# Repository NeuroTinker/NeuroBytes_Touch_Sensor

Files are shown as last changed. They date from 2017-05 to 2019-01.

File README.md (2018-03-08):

# NeuroBytes Touch Sensory Neuron
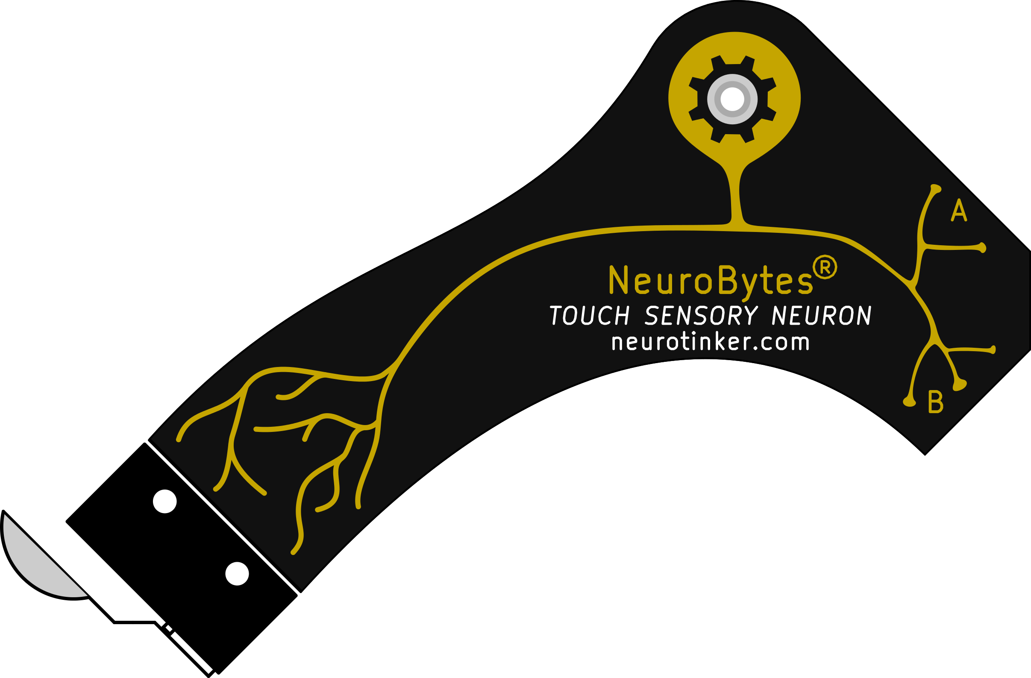
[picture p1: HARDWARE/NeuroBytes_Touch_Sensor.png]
NeuroBytes Touch Sensory Neuron PCB front

The NeuroBytes Touch Sensory Neuron is an open-source hardware neuron simulator designed and sold by [NeuroTinker, LLC](http://www.neurotinker.com/). 

All NeuroBytes products are based on the ST32L0x series of ARM Cortex-M0+ 32-bit microcontrollers. The boards were designed in KiCad and Inkscape and are released under the terms of the Creative Commons Attribution-ShareAlike 4.0 license, available here: http://creativecommons.org/licenses/by-sa/4.0/. The NeuroBytes Touch Sensory Neuron is Certified Open Source Hardware as defined by [OSHWA](https://www.oshwa.org), certification number US000110.


OSHWA Certification

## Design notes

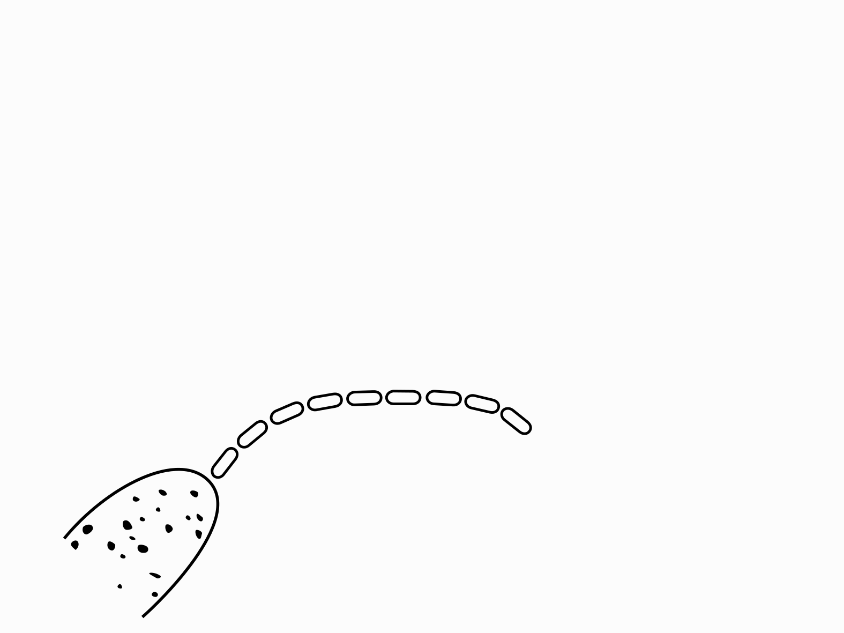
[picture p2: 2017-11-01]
HARDWARE/silk.png

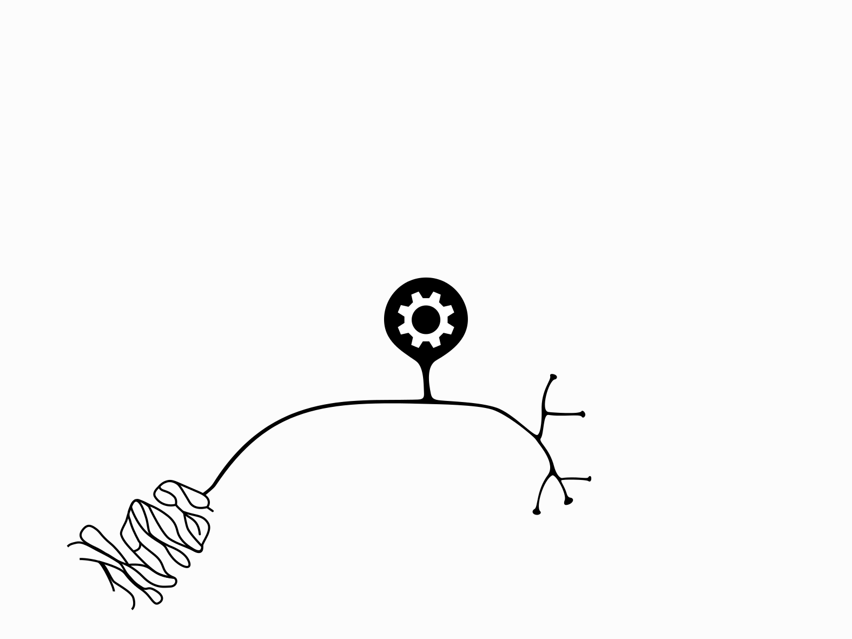
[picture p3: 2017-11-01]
HARDWARE/mask.png

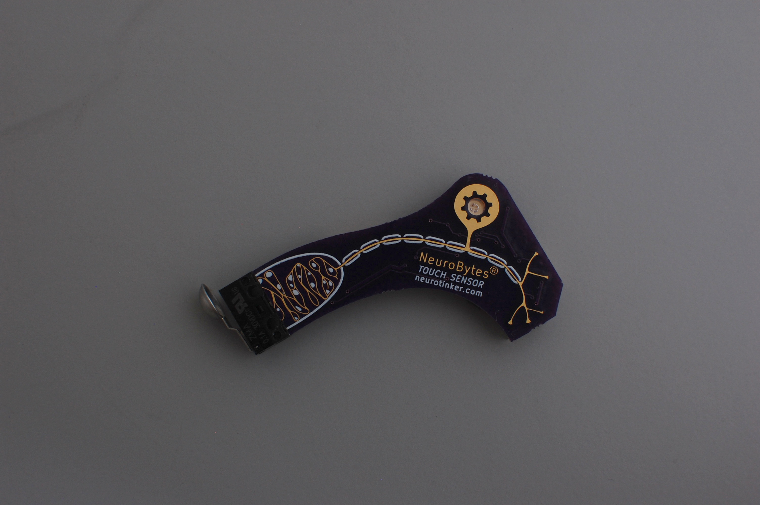
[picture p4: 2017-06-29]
HARDWARE/img_front.JPG

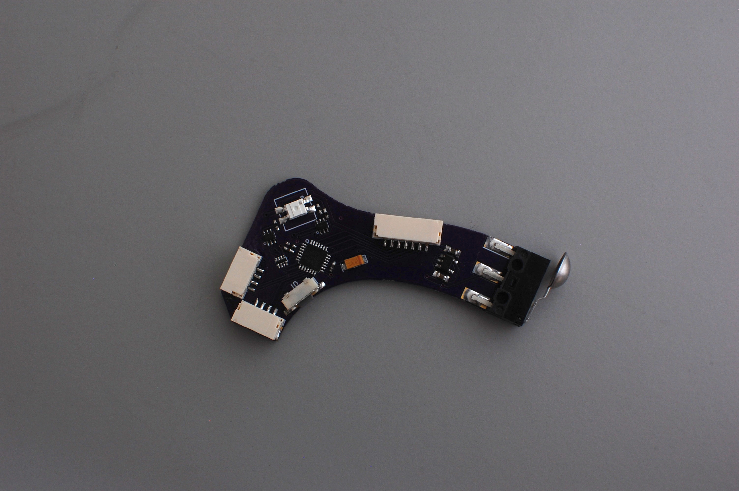
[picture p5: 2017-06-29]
HARDWARE/img_back.JPG

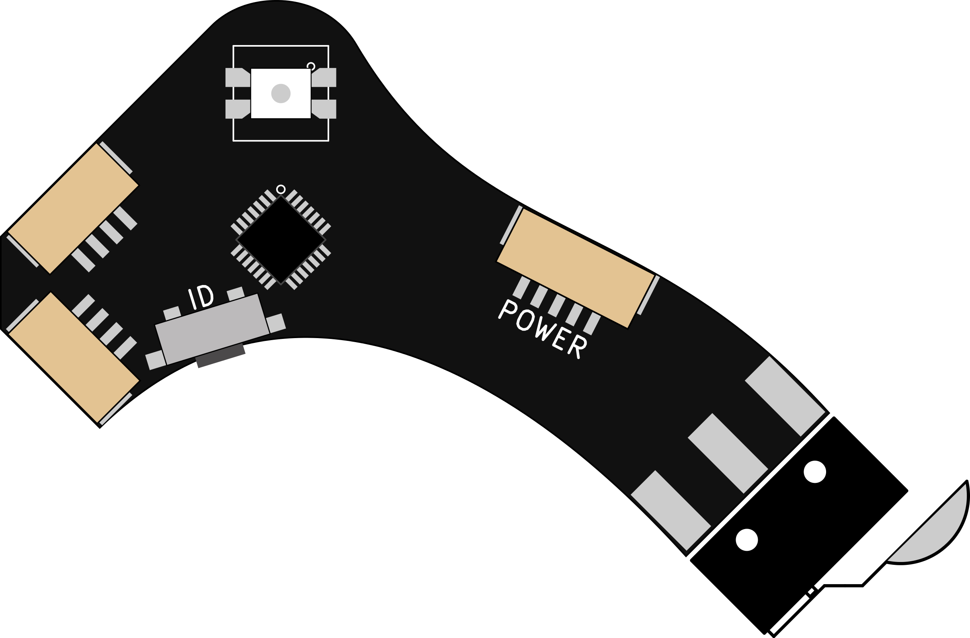
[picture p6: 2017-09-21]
HARDWARE/NeuroBytes_Touch_Sensor_back.png

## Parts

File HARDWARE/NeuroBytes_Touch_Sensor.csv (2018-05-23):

Ref | Qty | Value | Link | Mfr | Mfr Part # | Package | RoHS | Subs Allowed
C1 C4 | 2 | 1u | https://www.digikey.com/product-detail/en/taiyo-yuden/LMK107B7105KA-T/587-1242-2-ND/930594 | Taiyo Yuden | LMK107B7105KA-T | C0603 | Yes | Yes
C5 C3 | 2 | 0u1 | https://www.digikey.com/product-detail/en/taiyo-yuden/LMK105BJ104KV-F/587-1227-2-ND/930579 | Taiyo Yuden | LMK105BJ104KV-F | C0402 | Yes | Yes
C2 | 1 | 10u | https://www.digikey.com/product-detail/en/taiyo-yuden/EMK316B7106KL-TD/587-2395-2-ND/2178914 | Taiyo Yuden | EMK316B7106KL-TD | C1206 | Yes | Yes
D1 | 1 | LED_RABG | https://www.digikey.com/product-detail/en/sunled/XZMDKCBDDG45S-9/1497-1257-2-ND/4902045 | SunLED | XZMDKCBDDG45S-9 | SMT | Yes | No
P6 P7 | 2 | CONN_01X04 | https://www.digikey.com/product-detail/en/jst-sales-america-inc/SM04B-GHS-TB-LF-SN/455-1566-2-ND/807788 | JST | SM04B-GHS-TB(LF)(SN) | JST_GH_4-POS | Yes | No
P1 | 1 | JST_GH_5-pos | https://www.digikey.com/product-detail/en/jst-sales-america-inc/SM05B-GHS-TB-LF-SN/455-1567-2-ND/807789 | JST | SM05B-GHS-TB(LF)(SN) | SMT | Yes | No
Q1 Q2 Q3 | 3 | MMBT3904 | https://www.digikey.com/product-detail/en/micro-commercial-co/MMBT3904-TP/MMBT3904TPMSTR-ND/717280 | Micro Commercial Co | MMBT3904-TP | SOT23-3L | Yes | Yes
R1 | 1 | 150 | https://www.digikey.com/product-detail/en/yageo/RC0402FR-07150RL/311-150LRCT-ND/729490 | Yageo | RC0402FR-07150RL | R0402 | Yes | Yes
R2 R3 | 2 | 100 | https://www.digikey.com/product-detail/en/yageo/RC0402FR-07100RL/311-100LRTR-ND/726527 | Yageo | RC0402FR-07100RL | R0402 | Yes | Yes
R4 | 1 | JMP | https://www.digikey.com/product-detail/en/yageo/RC0402JR-070RL/311-0.0JRTR-ND/726406 | Yageo | RC0402JR-070RL | R0402 | Yes | Yes
R5 R6 R7 | 3 | 1k | https://www.digikey.com/product-detail/en/yageo/RC0402FR-071KL/311-1.00KLRTR-ND/726513 | Yageo | RC0402FR-071KL | R0402 | Yes | Yes
SW1 | 1 | SW_PUSH | https://www.digikey.com/product-detail/en/e-switch/TL3330AF130QG/EG4388TR-ND/1426835 | E-Switch | TL3330AF130QG | SMT | Yes | No
SW2 | 1 | SW_SNAP_ACTION | https://www.digikey.com/product-detail/en/c-k/ZMA00A080S06PC/CKN10156-ND/2044492 | C&K | ZMA00A080S06PC | THT (SMT side mtg) | Yes | No
U1 | 1 | STM32L011Gx | http://www.mouser.com/ProductDetail/STMicroelectronics/STM32L011G4U6/ | ST Microelectronics | STM32L011G4U6 | UFQFPN28 | Yes | No
U2 | 1 | 3v3 LDO | https://www.digikey.com/product-detail/en/on-semiconductor/NCP114BSN330T1G/NCP114BSN330T1GOSTR-ND/6560606 | ON Semiconductor | NCP114BSN330T1G | SOT23-5L | Yes | Yes
BOM made with KICAD_BOM_WIZARD (https://github.com/HashDefineElectronics/KiCad_BOM_Wizard.git)
Generated Wed 23 May 2018 05:36:58 PM CDT

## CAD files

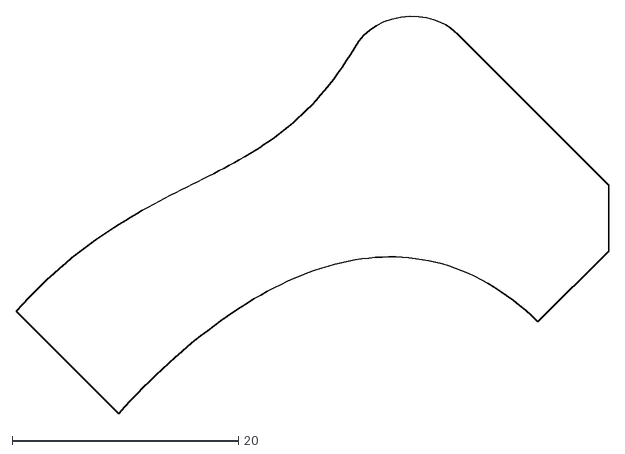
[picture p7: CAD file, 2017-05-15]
HARDWARE/NeuroBytes_Touch_Sensor.dxf
52.3 x 35.1

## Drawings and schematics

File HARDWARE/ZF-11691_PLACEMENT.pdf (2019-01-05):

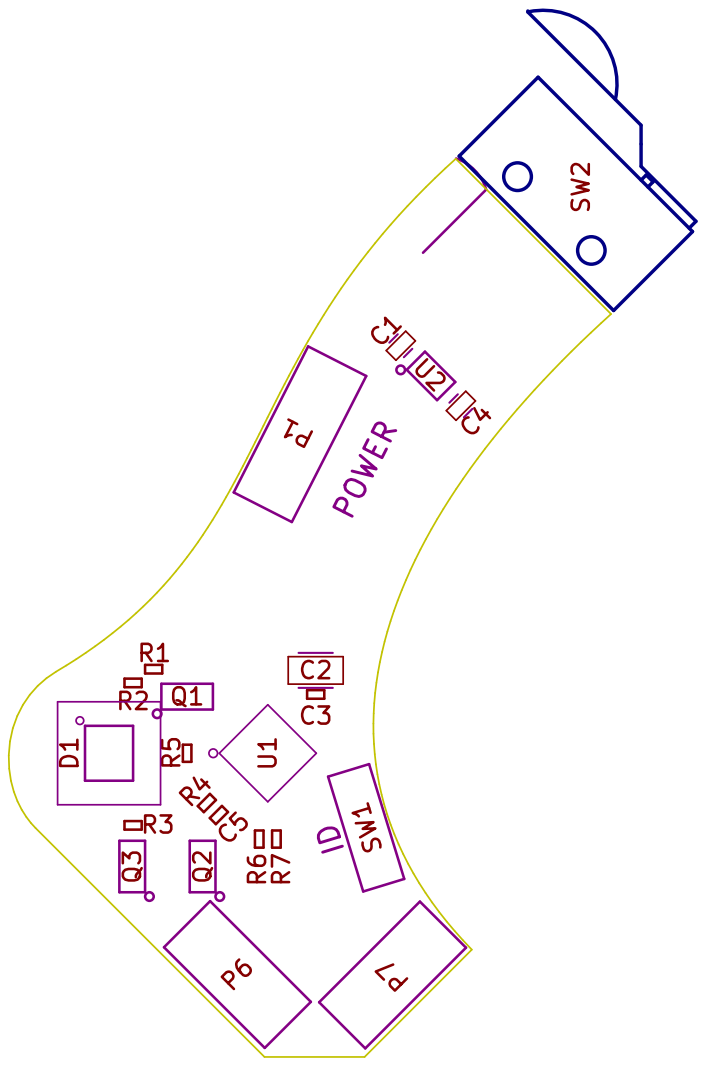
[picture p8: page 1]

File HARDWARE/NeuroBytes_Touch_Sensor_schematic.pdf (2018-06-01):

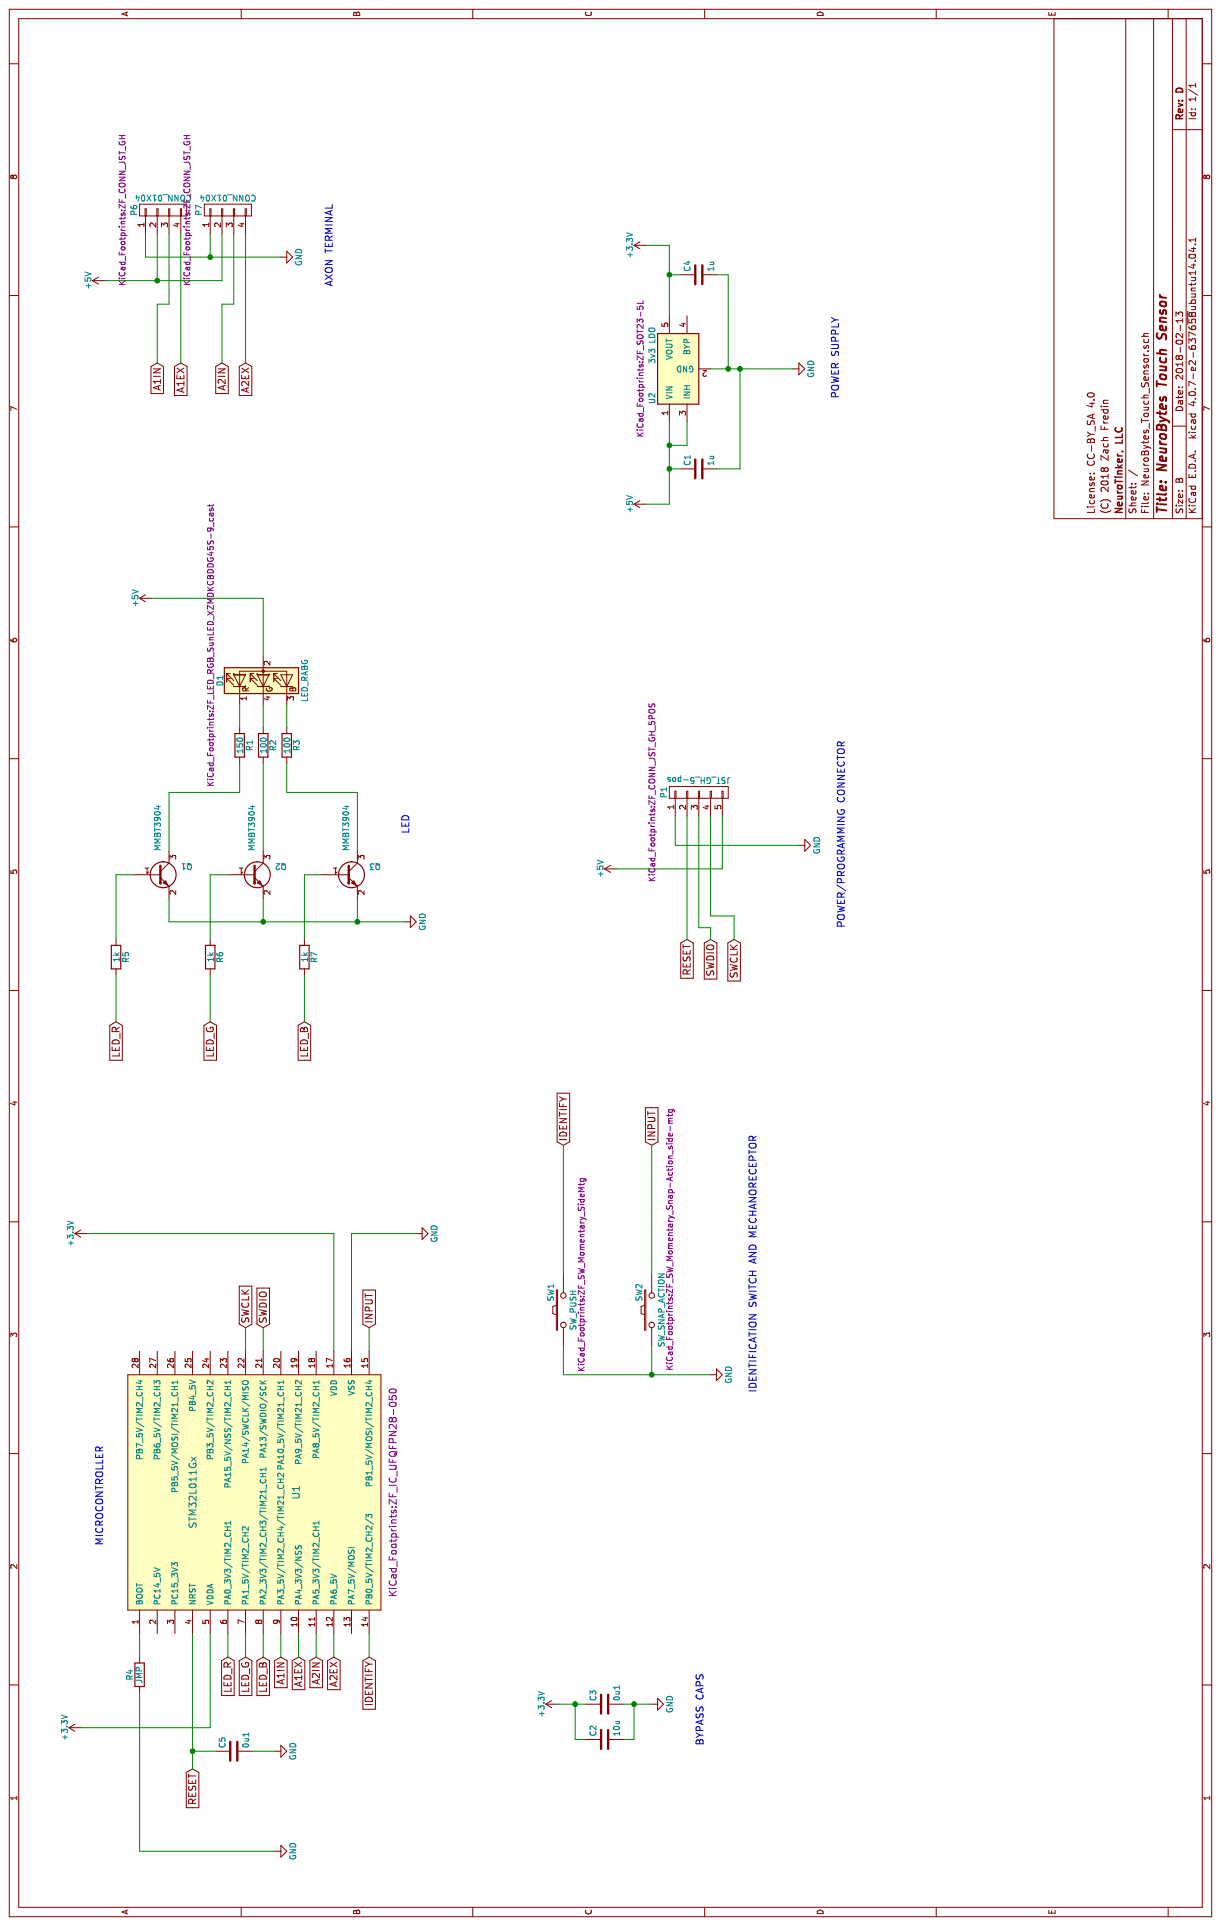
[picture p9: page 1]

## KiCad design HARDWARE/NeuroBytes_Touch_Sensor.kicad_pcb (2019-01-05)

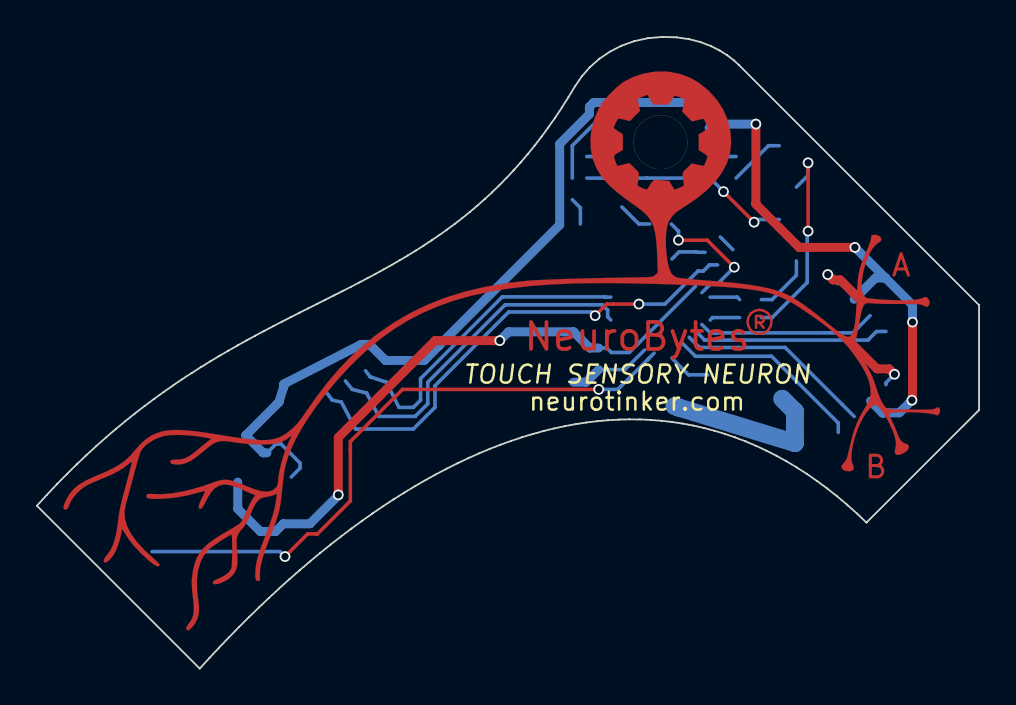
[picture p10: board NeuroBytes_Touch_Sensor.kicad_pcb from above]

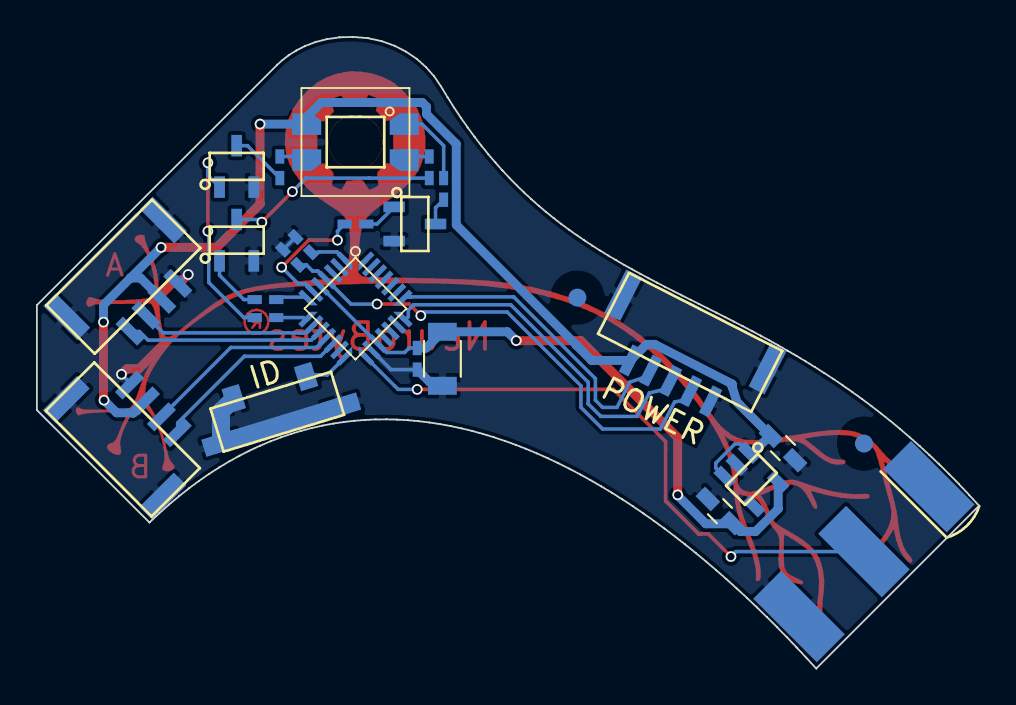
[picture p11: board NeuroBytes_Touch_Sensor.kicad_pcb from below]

Board: 2 copper layers, 52.3 x 35.1 mm, 23 parts (23 on the bottom side), 25 nets.

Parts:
C1, C4: 1u; C_0603_HandSoldering
C2: 10u; C_1206
C3, C5: 0u1; ZF_SMD_NonPol_0402_cap
D1: LED_RABG; ZF_LED_RGB_SunLED_XZMDKCBDDG45S-9_cast
P1: JST_GH_5-pos; ZF_CONN_JST_GH_5POS
P6, P7: CONN_01X04; ZF_CONN_JST_GH
Q1, Q2, Q3: MMBT3904; ZF_SOT23-3L
R1: 150; ZF_SMD_NonPol_0402
R2, R3: 100; ZF_SMD_NonPol_0402
R4: JMP; ZF_SMD_NonPol_0402
R5, R6, R7: 1k; ZF_SMD_NonPol_0402
SW1: SW_PUSH; ZF_SW_Momentary_SideMtg
SW2: SW_SNAP_ACTION; ZF_SW_Momentary_Snap-Action_side-mtg
U1: STM32L011Gx; ZF_IC_UFQFPN28-050
U2: 3v3 LDO; ZF_SOT23-5L

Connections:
+3V3: C2.1, C3.1, C4.1, U1.5, U1.17, U2.5
+5V: C1.1, D1.2, P1.5, P6.2, P7.2, U2.1, U2.3
A1EX: P6.4, U1.10
A1IN: P6.3, U1.9
A2EX: P7.4, U1.12
A2IN: P7.3, U1.11
GND: C1.2, C2.2, C3.2, C4.2, C5.2, P1.1, P6.1, P7.1, Q1.2, Q2.2, Q3.2, R4.1, SW1.1, SW2.1, U1.16, U2.2
IDENTIFY: SW1.2, U1.14
INPUT: SW2.2, U1.15
LED_B: R7.2, U1.8
LED_G: R6.2, U1.7
LED_R: R5.2, U1.6
unnamed: D1.1, R1.1
unnamed: D1.3, R3.1
unnamed: D1.4, R2.1
unnamed: Q1.1, R5.1
unnamed: Q1.3, R1.2
unnamed: Q2.1, R6.1
unnamed: Q2.3, R2.2
unnamed: Q3.1, R7.1
unnamed: Q3.3, R3.2
unnamed: R4.2, U1.1
RESET: C5.1, P1.2, U1.4
SWCLK: P1.4, U1.22
SWDIO: P1.3, U1.21

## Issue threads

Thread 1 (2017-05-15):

Need separate axons

jrwhite, 2017-05-15:
The axons currently share inhibitory/excitatory lines. Protocol implementation will improve fi these are separated.

jrwhite, 2017-05-16:
Schematic has been updated with latest board rev which has separate axons.
False alarm!

Closed 2017-05-16.

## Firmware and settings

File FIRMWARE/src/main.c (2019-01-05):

#define BUFSIZ 32

#include <libopencm3/stm32/rcc.h>
#include <libopencm3/stm32/gpio.h>
#include <libopencm3/stm32/timer.h>
#include <libopencm3/cm3/nvic.h>
#include <libopencm3/cm3/systick.h>
#include <libopencm3/stm32/exti.h>
#include <libopencm3/stm32/usart.h>

#include "HAL.h"
#include "comm.h"
#include "neuron.h"

#define BLINK_TIME			40
#define DATA_TIME			10
#define DEND_PING_TIME		200 // 1000 ms
#define	NID_PING_TIME		200 // 1000 ms
#define SEND_PING_TIME		80
#define BUTTON_PRESS_TIME	2
#define BUTTON_HOLD_TIME    100
#define LPUART_SETUP_TIME	100
#define CHANGE_NID_TIME 	200
#define MECHANORECEPTOR_PRESS_TIME	2
#define MECHANORECEPTOR_ADAPT_START	35
#define MECHANORECEPTOR_ADAPT_END	150

// #define DBG

int main(void)
{
	uint8_t		i;

	// counters
	uint32_t	blink_time = 0; // counter for LED blink due to NID command
	uint16_t	data_time = 0; // counter for sending data to NID
	uint16_t	send_ping_time = 0; // counter for sending a downstream ping
	uint16_t	fire_delay_time = 0;
	int16_t 	depression_time = 0;
	uint8_t		fire_flag = 0;
	uint8_t		change_nid_time = 0;
	int16_t		fire_data = 0; // hack to make sure a pulse sends peak neuron potential and hyperpolarization  data
	uint16_t	fire_delay_time_reset = FIRE_DELAY_TIME;
	fire_delay_time_reset = 40; // temporary
	uint16_t	fire_delay_overflow = 0; // used if firing period is less than delay time.
	uint16_t	lpuart_setup_time = 0;

	// button debounce variables
	uint16_t	button_press_time = 0; 
	uint8_t		button_armed = 0;
	uint16_t	button_status = 0;

	uint16_t	mechanoreceptor_press_time = 0;
	uint16_t	mechanoreceptor_status = 0;
	uint32_t	mechanoreceptor_adapt_count = 0;
	uint32_t 	mechanoreceptor_adapt_reset = 0;

	message_t	message; // staging variable for constructing messages to send to the communications routine

	int32_t joegenta = 0;

	//char output[10] = "test";

	// initialize neuron
	neuron_t 	neuron;
	neuronInit(&neuron);

	neuron.dendrites[0].magnitude = 15000;
	neuron.dendrites[0].base_magnitude = 15000;

	// initialize communication buffers
	commInit();

	// setup hardware
	clock_setup();
	systick_setup(); // systick in microseconds
	gpio_setup();
	tim_setup();

	// main processing routine	
	for(;;)
	{
		if (main_tick == 1 && pause_flag == 0){
			// main tick every 5 ms
			main_tick = 0;
			//gpio_set(PORT_AXON1_EX, PIN_AXON1_EX);

			// check to see if nid ping hasn't been received in last NID_PING_TIME ticks
			if (nid_ping_time > 0){
				nid_ping_time -= 1;
				if (nid_ping_time == 0){
					// nid no longer connected
					nid_distance = 100; // reset nid_keep_alive
					nid_pin = 0; // clear the nid pin
					nid_pin_out = 0;
					nid_i = NO_NID_I;
				}
			}
			
			if (change_nid_time++ > CHANGE_NID_TIME){
				change_nid_time = 0;
				closer_distance = nid_distance;
				closer_ping_count = 0;
			}

			// send a downstream ping every SEND_PING_TIME ticks
			if (send_ping_time++ > SEND_PING_TIME){
				// send downstream ping through axon
				addWrite(DOWNSTREAM_BUFF, downstream_ping_message);
				send_ping_time = 0;
			}

			if (lpuart_setup_time < LPUART_SETUP_TIME){
				lpuart_setup_time += 1;
			} else if (lpuart_setup_time == LPUART_SETUP_TIME){
				lpuart_setup_time += 1;
				#ifndef DBG
				lpuart_setup();
				#endif
			}

			/*
				nid_channel is the current channel, if any, that the NeuroByte is using to communicate
				with the NID. nid_channel should be cleared when NID tries to set a new NeuroByte to 
				identify_channel.

				The communication routine sets identify_time to zero when a new identify command is received.
			*/

			// check for clear channel command
			if (identify_time < IDENTIFY_TIME){
				if (identify_time == 0){
					if ((identify_channel == 0) || (identify_channel == nid_channel)){
						nid_channel = 0;
					}
				}
				identify_time += 1;
			}

			// check buttons
			button_status = gpio_get(PORT_IDENTIFY, PIN_IDENTIFY); 
			mechanoreceptor_status = gpio_get(PORT_MECHANORECEPTOR, PIN_MECHANORECEPTOR);

			// if identify button is pressed and identify_time < IDENTIFY_TIME (i.e. NID sent 'identify'' message), set new nid_channel
			if (button_status == 0){
				// debounce
				button_press_time += 1;
				if (button_press_time >= BUTTON_HOLD_TIME){
					button_armed = 2;
					// blink_flag = 1;
				} else if (button_press_time >= BUTTON_PRESS_TIME){
					button_armed = 1;
				}
			} else{
				// button not pressed
				if (button_armed == 0){
					button_press_time = 0;
				} else if (button_armed == 1 && nid_i != NO_NID_I){
					nid_channel = identify_channel;
					message.length = 32;
					message.message = (((uint32_t) DATA_TYPE_MESSAGE) | (((uint32_t) nid_channel) << 22));
					message.message |=  ((const uint16_t) (getFingerprint()));
					addWrite(NID_BUFF, (const message_t) message);
					identify_time = 1;
					button_armed = 0;
				} else if (button_armed == 2){
					// put button held logic here
					button_armed = 0;
				}
				button_press_time = 0;
			}
		
			if (mechanoreceptor_status == 0){
				//debounce
				mechanoreceptor_press_time += 1;
				if (mechanoreceptor_press_time >= MECHANORECEPTOR_PRESS_TIME){
					if (mechanoreceptor_adapt_count == 0) {
						neuron.dendrites[0].type = EXCITATORY;
						neuron.dendrites[0].state = ON;
						neuron.dendrites[0].pulse_time = 0;	
					}
					// mechanoreceptor_adapt_count++;
					if (mechanoreceptor_adapt_count > mechanoreceptor_adapt_reset) {
						mechanoreceptor_adapt_count = 0;
						if (mechanoreceptor_adapt_reset < MECHANORECEPTOR_ADAPT_END) {
							mechanoreceptor_adapt_reset <<= 4;
							mechanoreceptor_adapt_reset /= 15;
						}
					}			
				}	
			} else{
				mechanoreceptor_adapt_reset = MECHANORECEPTOR_ADAPT_START;
				mechanoreceptor_adapt_count = 0;
				mechanoreceptor_press_time = 0;
			}	

			// send current membrane potential to NID if currently identified by NID
			if (nid_channel != 0){
				// send data every DATA_TIME ticks
				if (data_time++ > DATA_TIME){
					if (fire_data > 0){
						if (fire_data == 1){
							message.message = (((uint32_t) DATA_MESSAGE)) | ((uint16_t) HYPERPOLARIZATION);
							fire_data = 0;						
						} else {
							message.message = (((uint32_t) DATA_MESSAGE)) | ((uint16_t) fire_data);	
							fire_data = 1;						
						}
					} else {
						message.message = (((uint32_t) DATA_MESSAGE)) | ((uint16_t) neuron.potential);						
					}
					data_time = 0;
					message.length = 32;
					message.message |= (nid_channel << 22);
					addWrite(NID_BUFF,(const message_t) message);
				}
			}

			// decay old dendrite contributions to the membrane potential
			dendriteDecayStep(&neuron);
			// decay the firing potential
			membraneDecayStep(&neuron);

			// current membrane potential comes from dendrites and any left over firing potential
			neuron.potential = calcNeuronPotential(&neuron);
			neuron.potential += neuron.fire_potential;
			neuron.fire_potential += neuron.leaky_current;

			// if membrane potential is greater than threshold, fire
			if (neuron.potential > MEMBRANE_THRESHOLD){
				// fire for determined pulse width
				neuron.state = FIRE;
				neuron.fire_potential = HYPERPOLARIZATION;
				neuron.fire_time = PULSE_LENGTH;
				for (i=0; i<NUM_DENDS; i++){
					neuron.dendrites[i].current_value = 0;
					neuron.dendrites[i].state = OFF;
				}

				fire_data = neuron.potential; // hack to send fire data to NID

				// send downstream pulse
				if (fire_delay_time == 0){
					fire_delay_time = fire_delay_time_reset;
					fire_delay_overflow = 0;
				} else {
					fire_delay_overflow = fire_delay_time_reset - fire_delay_time;
				}
				fire_flag = 1;
			} else if (neuron.potential < HYPERPOLARIZATION) {
				neuron.potential = HYPERPOLARIZATION;
			}

			if (fire_delay_time > 0){
				fire_delay_time -= 1;
			} else if (fire_flag == 1){
				if (fire_delay_overflow > 0)
					fire_delay_time = fire_delay_overflow; // TODO: make this an actual FIFO buffer of fire timings
				fire_flag = 0;
				addWrite(DOWNSTREAM_BUFF, pulse_message);
			}

			/*
				LED is either:
				-blinking due to NID message (blink_flag is set)
				-full white if neuron is firing
				-in an RGB state mapped to membrane potential
			*/
			
			if (blink_flag != 0){
				setLED(200,0,300);
				blink_time = 1;
				blink_flag = 0;
			} else if (blink_time > 0){
				if (++blink_time == BLINK_TIME){
					setLED(200,0,200);
					blink_time = 0;
				}
			} else if (neuron.state == FIRE){
				neuron.fire_time -= 1;
				if (neuron.fire_time == 0){
					neuron.state = INTEGRATE;
				}
				if (neuron.learning_state == HEBB){
					// needs to vary between 50 and 320
					joegenta /= 256;
					joegenta *= 3;
					joegenta += 100;
					if (joegenta > 350) joegenta = 350;
					setLED(joegenta, joegenta, joegenta);
				} else{
					LEDFullWhite();
				}
			} else if (neuron.state == INTEGRATE){
				if (neuron.potential > 10000){
					setLED(200,0,0);
				} else if (neuron.potential > 0){
					setLED(neuron.potential / 50, 200 - (neuron.potential / 50), 0);
				} else if (neuron.potential < -10000){
					setLED(0,0, 200);
				} else if (neuron.potential < 0){
					setLED(0, 200 + (neuron.potential / 50), -1 * neuron.potential / 50);
				} else{
					setLED(0,200,0);
				}
			}
		}
	}
}

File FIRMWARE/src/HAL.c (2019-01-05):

#include "HAL.h"

volatile uint8_t tick = 0;
volatile uint8_t main_tick = 0;
volatile uint8_t read_tick = 0;

volatile uint16_t active_input_pins[NUM_INPUTS] = {[0 ... NUM_INPUTS-1] = 0};

volatile uint8_t active_input_tick[NUM_INPUTS] = {[0 ... NUM_INPUTS-1] = 0};

volatile uint16_t active_output_pins[NUM_INPUTS] = {PIN_AXON1_EX, PIN_AXON2_EX};

volatile uint32_t dendrite_pulses[NUM_DENDS] = {[0 ... NUM_DENDS-1] = 0};
volatile uint8_t dendrite_pulse_count = 0;

/* 

All available input pins are:

PIN_AXON1_IN,
PIN_AXON2_IN,

*/

uint32_t active_input_ports[NUM_INPUTS] = {
    PORT_AXON1_IN,
    PORT_AXON2_IN,
};

uint32_t active_output_ports[NUM_INPUTS] = {
    PORT_AXON1_EX,
    PORT_AXON2_EX,
};

const uint16_t complimentary_pins[NUM_INPUTS] = {
    PIN_AXON1_EX,
    PIN_AXON2_EX,
};

const uint32_t complimentary_ports[NUM_INPUTS] = {
    PORT_AXON1_EX,
    PORT_AXON2_EX,
};

volatile uint8_t dendrite_pulse_flag[NUM_INPUTS] = {[0 ... NUM_INPUTS-1] = 0};
volatile uint8_t dendrite_ping_flag[NUM_INPUTS] = {[0 ... NUM_INPUTS-1] = 0};


static const uint32_t fingerprint[3] __attribute__((section (".fingerprint"))) __attribute__ ((__used__)) = {
	5, // device id
	2, // firmware version
	0  // unique id
};

bool checkVersion(device_id, version) {return (device_id == fingerprint[0]) && (version = fingerprint[1]) ? true : false;}

void clock_setup(void)
{
	// STM32F0 command:	rcc_clock_setup_in_hsi_out_48mhz();
	rcc_set_sysclk_source(RCC_HSI16);
	rcc_osc_on(RCC_HSI16);
}

void sys_tick_handler(void)
{
    if (++tick >= 50){
		main_tick = 1;
		tick = 0;
	}

	if (read_tick++ >= 2){
		writeBit();
		read_tick = 0;
	}

	readBit(read_tick);
	
    MMIO32((TIM21_BASE) + 0x10) &= ~(1<<0); //clear the interrupt register
}

void systick_setup()
{
    systick_set_clocksource(STK_CSR_CLKSOURCE_EXT);
    STK_CVR = 0;
    //systick_set_reload(2 * xms);
	systick_set_reload(180); //180
    systick_counter_enable();
    systick_interrupt_enable();
}

void gpio_setup(void)
{
	/*	Enable GPIO clocks */
	rcc_periph_clock_enable(RCC_GPIOA);
	rcc_periph_clock_enable(RCC_GPIOB);
	rcc_periph_clock_enable(RCC_GPIOC);

	rcc_peripheral_enable_clock(&RCC_APB2ENR, RCC_APB2ENR_SYSCFGEN); // this line took a long time


	/*	Set up LED pins, NeuroBytes v1.01:
		Alternative Function Mode with no pullup/pulldown
		Output options: push-pull, high speed
		PIN_R_LED (PA2): AF2, TIM2_CH3
		PIN_G_LED (PA5): AF5, TIM2_CH1
		PIN_B_LED (PA3): AF2, TIM2_CH4 
	*/
	
	gpio_mode_setup(PORT_LED, GPIO_MODE_AF, GPIO_PUPD_NONE, PIN_R_LED | PIN_G_LED | PIN_B_LED);
	gpio_set_output_options(PORT_LED, GPIO_OTYPE_PP, GPIO_OSPEED_HIGH, PIN_R_LED | PIN_G_LED | PIN_B_LED);
	gpio_set_af(PORT_LED, GPIO_AF2, PIN_R_LED | PIN_G_LED);
	gpio_set_af(PORT_LED, GPIO_AF2, PIN_B_LED);
	
	/* 
		Setup axon pins:
		Axon Excitatory PA10 TIM21_CH1	(temporarily output)
		Axon Inhibitory PA9  TIM21_CH2	(temporarily input)
	*/
	
	gpio_mode_setup(PORT_AXON1_EX, GPIO_MODE_OUTPUT, GPIO_PUPD_PULLDOWN, PIN_AXON1_EX);
	gpio_mode_setup(PORT_AXON1_IN, GPIO_MODE_INPUT, GPIO_PUPD_NONE, PIN_AXON1_IN);
	gpio_mode_setup(PORT_AXON2_EX, GPIO_MODE_OUTPUT, GPIO_PUPD_PULLDOWN, PIN_AXON2_EX);
	gpio_mode_setup(PORT_AXON2_IN, GPIO_MODE_OUTPUT, GPIO_PUPD_PULLDOWN, PIN_AXON2_IN);
	
	setAsInput(PORT_AXON1_IN, PIN_AXON1_IN);
	setAsOutput(PORT_AXON1_EX, PIN_AXON1_EX);
	setAsInput(PORT_AXON2_IN, PIN_AXON2_IN);
	setAsOutput(PORT_AXON2_EX, PIN_AXON2_EX);
	
	gpio_mode_setup(PORT_MECHANORECEPTOR, GPIO_MODE_INPUT, GPIO_PUPD_PULLUP, PIN_MECHANORECEPTOR);
	gpio_mode_setup(PORT_IDENTIFY, GPIO_MODE_INPUT, GPIO_PUPD_PULLUP, PIN_IDENTIFY);
	
	nvic_enable_irq(NVIC_EXTI0_1_IRQ);
	nvic_enable_irq(NVIC_EXTI2_3_IRQ);
	nvic_enable_irq(NVIC_EXTI4_15_IRQ);

	nvic_set_priority(NVIC_EXTI0_1_IRQ, 0);
	nvic_set_priority(NVIC_EXTI2_3_IRQ, 0);
	nvic_set_priority(NVIC_EXTI4_15_IRQ, 0);
}

void lpuart_setup(void)
{
	// seutp lpuart interface (for communicating with NID)
	// NOTE: this ocnverts the swd interface to lpuart so debugging with swd will be disables
	rcc_periph_clock_enable(RCC_LPUART1);

	gpio_mode_setup(PORT_LPUART1_RX, GPIO_MODE_AF, GPIO_PUPD_NONE, PIN_LPUART1_RX);
	gpio_mode_setup(PORT_LPUART1_TX, GPIO_MODE_AF, GPIO_PUPD_NONE, PIN_LPUART1_TX);

	gpio_set_af(PORT_LPUART1_RX, GPIO_AF6, PIN_LPUART1_RX);
	gpio_set_af(PORT_LPUART1_TX, GPIO_AF6, PIN_LPUART1_TX);

	USART_BRR(LPUART1) = 0x1A0AA; // 38400 baud
	usart_set_databits(LPUART1, 8);  // USART_CR1_M
	usart_set_stopbits(LPUART1, USART_STOPBITS_1); //USART_CR2_STOP
	usart_set_mode(LPUART1, USART_MODE_TX_RX); //USART_CR1_RE USART_CR1_TE
	usart_set_parity(LPUART1, USART_PARITY_NONE);// USART_CR1_PS USART_CR1_PCE
	usart_set_flow_control(LPUART1, USART_FLOWCONTROL_NONE); // USART_CR3_RTSE USART_CR3_CTSE

	usart_enable(LPUART1); // USART_CR1_UE

	// enable interrupts
	nvic_enable_irq(NVIC_LPUART1_IRQ);
	usart_enable_rx_interrupt(LPUART1); // USART_CR1_RXNEIE
    USART_CR1(LPUART1) |= USART_CR1_RE;
    USART_CR1(LPUART1) |= USART_CR1_TE;
}

void lpuart1_isr(void)
{
    if ((USART_ISR(LPUART1) & USART_ISR_RXNE) != 0){
        readNID();
        USART_RQR(LPUART1) = 0b1000;
        USART_CR1(LPUART1) |= USART_CR1_RE;
    } else if ((USART_ISR(LPUART1) & USART_ISR_TXE) != 0){
        /* USART_CR1(LPUART1) |= USART_CR1_TE; */
        writeNID();
        USART_RQR(LPUART1) |= USART_RQR_TXFRQ;
    }
    USART_ICR(LPUART1) = USART_ISR(LPUART1);
}

void setAsInput(uint32_t port, uint32_t pin)
{
	// setup gpio as an input pin
	gpio_mode_setup(port, GPIO_MODE_INPUT, GPIO_PUPD_PULLDOWN, pin);
	gpio_set_output_options(port, GPIO_OTYPE_PP, GPIO_OSPEED_LOW, pin);

	// setup interrupt for the pin going high
	exti_select_source(pin, port);
	exti_set_trigger(pin, EXTI_TRIGGER_RISING);
	exti_enable_request(pin);
	exti_reset_request(pin);
}

void setAsOutput(uint32_t port, uint32_t pin)
{
	// disable input interrupts
	exti_disable_request(pin);

	// setup gpio as an output pin. pulldown
	gpio_mode_setup(port, GPIO_MODE_OUTPUT, GPIO_PUPD_PULLDOWN, pin);
}

// working interrupt pins: 0,1,3,4,6,7

/*
	Each input's ISR tells the communications program that the input is active (getting a message).
	For dendrite inputs, the ISR also tells the neuron program if the input is excitatory or inhibitory and then toggles input/output
*/

void exti0_1_isr(void)
{
	// interrupt handler for pins 0,1
}

void exti2_3_isr(void)
{
	// interrupt handler for pins 2,3
	if ((EXTI_PR & PIN_AXON1_IN) != 0){
		// pin 3
		ACTIVATE_INPUT(0, PIN_AXON1_IN);
		EXTI_PR |= PIN_AXON1_IN;
	}
}

void exti4_15_isr(void)
{
	// interrupt handler for pins 4-15
	//setLED(0,0,200);
	//gpio_toggle(PORT_AXON_OUT, PIN_AXON_OUT);
	if ((EXTI_PR & PIN_AXON2_IN) != 0){
		// pin 5
		active_input_pins[1] = PIN_AXON2_IN;
		ACTIVATE_INPUT(1, PIN_AXON2_IN);
		EXTI_PR |= PIN_AXON2_IN;
	}
}
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

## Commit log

2017-04-24 Initial commit -- first rev HW and test FW.
    [NeuroBytes_Touch_Sensor.dxf, NeuroBytes_Touch_Sensor.kicad_pcb, NeuroBytes_Touch_Sensor.sch]
2017-05-15 added schematic library submodule
2017-05-15 Board rev2. Simplified PCB outline and modified axon graphics a bit.
    [NeuroBytes_Touch_Sensor.dxf, NeuroBytes_Touch_Sensor.kicad_pcb, NeuroBytes_Touch_Sensor.sch]
2017-05-15 updated firmware for new board revision
2017-05-16 Updated PCB footprints to proper rotations. Added fab documentation to PCB file. Generated Gerber files, drill file, and placement file. Generated and filled in BOM. Added switch graphic to PCB dwgs 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
    [NeuroBytes_Touch_Sensor-B.Cu.gbr, NeuroBytes_Touch_Sensor-B.Fab.gbr, NeuroBytes_Touch_Sensor-B.Mask.gbr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]
2017-05-17 Minor Gerber file updates. Removed paste from SW2 (snap-action) footprint.
    [NeuroBytes_Touch_Sensor-B.Cu.gbr, NeuroBytes_Touch_Sensor-B.Fab.gbr, NeuroBytes_Touch_Sensor-B.Mask.gbr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]
2017-05-18 Added front and back pictures of Rev. B PCBs. Minor photo touch-ups to clean table (mostly junk on the lens) and adjust levels.
2017-06-02 Updated switch and connector footprints. Changed out dual transistors and resistor network for discrete components. Other minor updates.
    [NeuroBytes_Touch_Sensor.csv, NeuroBytes_Touch_Sensor.kicad_pcb, NeuroBytes_Touch_Sensor.sch]
2017-08-11 Switched to 5-pin power/programming connector. Added POWER text and increased ID text size. Changed to TOUCH SENSORY NEURON. Added dendrite ID letters.
    [NeuroBytes_Touch_Sensor.kicad_pcb, NeuroBytes_Touch_Sensor.sch]
2017-08-11 added fingerprint
2017-08-11 fingerprint address
2017-08-11 update fingerprint
2017-08-28 added kicad fonts to *.svg. added *.png render of pcb front.
2017-09-22 deleted old Gerber files. fresh board front export.
    [NeuroBytes_Touch_Sensor-B.Cu.gbr, NeuroBytes_Touch_Sensor-B.Fab.gbr, NeuroBytes_Touch_Sensor-B.Mask.gbr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]
2017-09-22 update schematic lib
2017-09-22 updated gear shape to new design on PCB and *.svg. pulled mask back on labels. updated schematic part descriptions. fresh BOM export. other minor updates.
    [NeuroBytes_Touch_Sensor.csv, NeuroBytes_Touch_Sensor.kicad_pcb, NeuroBytes_Touch_Sensor.sch]
2017-09-22 reloaded netlist. minor PCB updates.
    [NeuroBytes_Touch_Sensor.kicad_pcb]
2017-09-27 updated to minimally modified Interneuron firmware to maintain consistency across boards (new membrane potential range, LED color scheme, comments, variable locations, etc). added adaptation mode.
2017-10-03 minor page layout updates
    [NeuroBytes_Touch_Sensor.kicad_pcb, NeuroBytes_Touch_Sensor.sch]
2018-02-13 added ESD protection. minor routing changes. updated title block.
    [NeuroBytes_Touch_Sensor.kicad_pcb, NeuroBytes_Touch_Sensor.sch]
2018-03-06 added ESD protection. updated graphics.
    [NeuroBytes_Touch_Sensor.kicad_pcb]
2018-03-08 updated PCB renders (no myelination, etc). updated license/readme.
2018-05-23 generated fab and BOM files
    [NeuroBytes_Touch_Sensor-B.Cu.gbr, NeuroBytes_Touch_Sensor-B.Mask.gbr, NeuroBytes_Touch_Sensor-B.Paste.gbr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]
2018-05-31 added schematic *.pdf export
2018-06-19 fixed comms slowing bug
    [HAL.c, main.c]
2018-08-06 added placement diagram for PCBA
2018-08-06 updated 0603 and 1206 footprints. minor routing fix. added placement pdf.
    [NeuroBytes_Touch_Sensor.kicad_pcb, NeuroBytes_Touch_Sensor.sch]
2018-08-06 re-generated Gerber files
    [NeuroBytes_Touch_Sensor-B.Cu.gbr, NeuroBytes_Touch_Sensor-B.Fab.gbr, NeuroBytes_Touch_Sensor-B.Mask.gbr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]
2018-08-08 regen drill file
    [NeuroBytes_Touch_Sensor.drl]
2018-08-08 deleted duplicate drill file
    [NeuroBytes_Touch_Sensor.drl]
2019-01-05 fixed #*$&ing regulator rotation that caused delays and resulted in much scrap
    [NeuroBytes_Touch_Sensor-2018-10-08-12-36-10.sch, NeuroBytes_Touch_Sensor-2019-01-04-17-42-30.sch, NeuroBytes_Touch_Sensor-2019-01-04-21-25-31.sch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]

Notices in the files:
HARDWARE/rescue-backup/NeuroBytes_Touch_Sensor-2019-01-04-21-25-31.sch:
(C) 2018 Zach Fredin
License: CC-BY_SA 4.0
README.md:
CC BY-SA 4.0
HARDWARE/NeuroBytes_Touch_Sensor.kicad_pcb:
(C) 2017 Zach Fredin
